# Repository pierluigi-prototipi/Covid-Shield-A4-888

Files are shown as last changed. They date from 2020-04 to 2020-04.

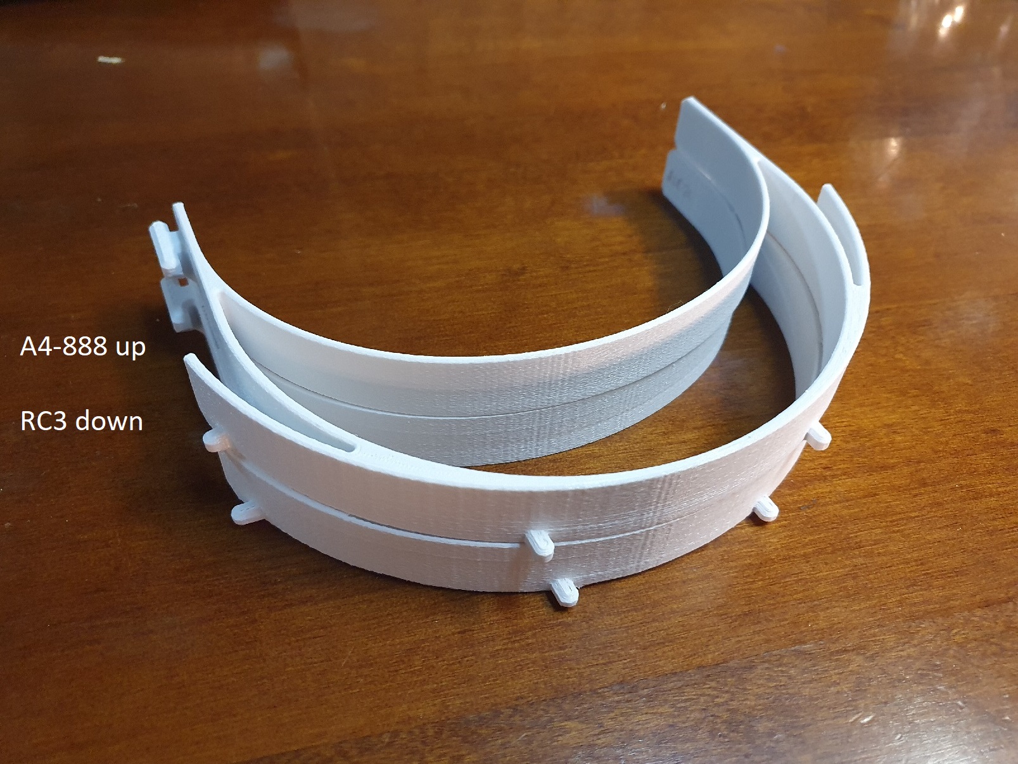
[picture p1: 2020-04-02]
confronto A4-888 vs RC3.jpg

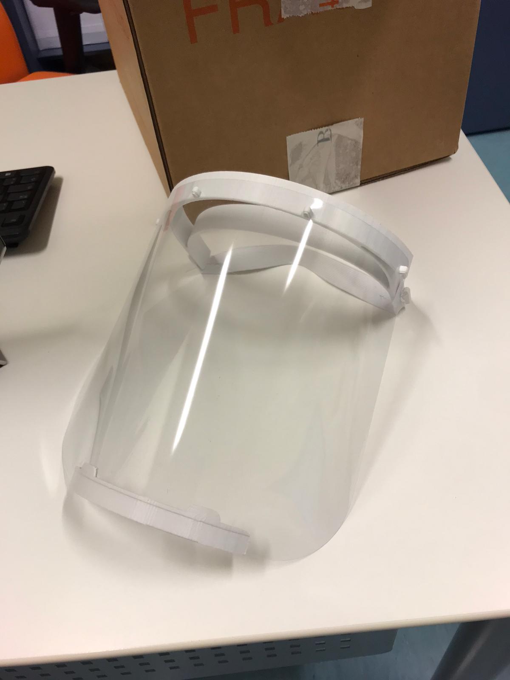
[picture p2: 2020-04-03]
foto scudo.jpeg

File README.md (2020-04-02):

# Covid-Shield-A4-888
A protective face shield based on A4 acetate sheet with holes spaced of 8 cm. You find more instructions on the pdf drawing.

The starting point of this design is the famous Prusa Protective FaceShield RC3. Because I found difficult to cut the holes on a A4 sheet in the correct position with the original design I modified it.
Here the major changes from the Prusa RC3:

HEAD-BAND:
1) It is larger in order to fit a 260 mm width sheet (I cut the A4 sheets, but if you prefer can leave them as they are)
2) The distance between the pins has been modified in order to fit a 8-8-8 cm preforated A4 sheet
3) The external pins are slightly shorter to simplify the linking to the sheet.
4) Removed all the slots, including the engraved writings, in order to avoid impurity retention.

Lower renforcement:
1) Now is a 2 pin design to make easier the punches on sheet.
2) The pin are longer and with two differnt slope on the upper and the lower side of the pins, to augment the stability on the sheet without reducing too much the ease of assembly.

SHIELD:
1) The starting point that I use is a common A4 acetate sheet, about 0.2 mm thick. Maybe a major thickness would be preferable.

THIS EQUIPMENT HAS NOT BEEN PROFESSIONALLY TESTED AND IS NOT CERTIFIED! Nevertheless I printed about twenty pieces in PLA and I find it usable, but this is just my opinion.

VERSIONE ITALIANA: 

 Visiera protettiva basata su foglio A4 in acetato con fori distanziati di 8 cm. Le istruzioni per tagliare i fogli sono disponibili     nel disegno pdf.

Il punto di partenza di questo progetto è il famoso Prusa Protector FaceShield RC3. Poichè ho trovato difficile eseguire i fori su un foglio A4 nella posizione corretta con il design originale, l'ho modificato, arrivando al modello che allego.
Ecco i principali cambiamenti rispetto al Prusa RC3:

FASCIA PER LA TESTA:
1) È leggermente più grande per adattarsi a un foglio di larghezza 260 mm (Rifilo i fogli A4 a 260 mm, ma se preferite si possono lasciare di 297 mm).
2) La distanza tra i perni è stata modificata per adattarsi a un foglio A4 preforato a 8-8-8 cm.
3) I pin esterni sono leggermente più corti per semplificare il collegamento al foglio.
4) Rimosse tutte le tasche, incluse le scritte incise, per evitare zone di possibile deposito di impurità.

Rinforzo inferiore:
1) Ora ha un design a 2 pin per facilitare la perforatura del foglio grazie all'utilizzo della spaziatura standard italiana di 8 cm.
2) I pin sono più lunghi e con due inclinazioni differenti sul bordo inferiore e superiore, al fine di rendere più solido il collegamento al foglio, senza compromettere eccessivamente la facilità di montaggio.

SCUDO:
1) Il punto di partenza è un comune foglio di acetato A4, spesso circa 0,2 mm. Forse sarebbe preferibile uno spessore maggiore.

QUESTO DISPOSITIVO NON E' STATO TESTATO PROFESSIONALMENTE E NON E' CERTIFICATO! Nonostante ciò ho stampato circa una ventina di pezzi in PLA e li trovo perfettamente utilizzabili. Ma questa è una mia opinione.

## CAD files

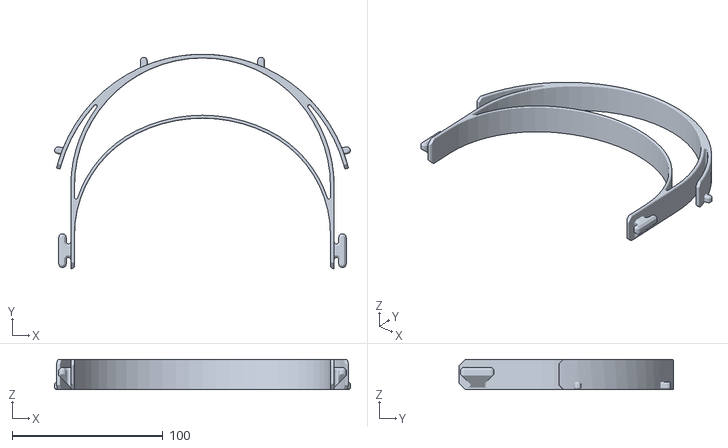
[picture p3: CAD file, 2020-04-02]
COVID_HEADBAND_A4-888_x1.stl
196.6 x 142.5 x 20.0

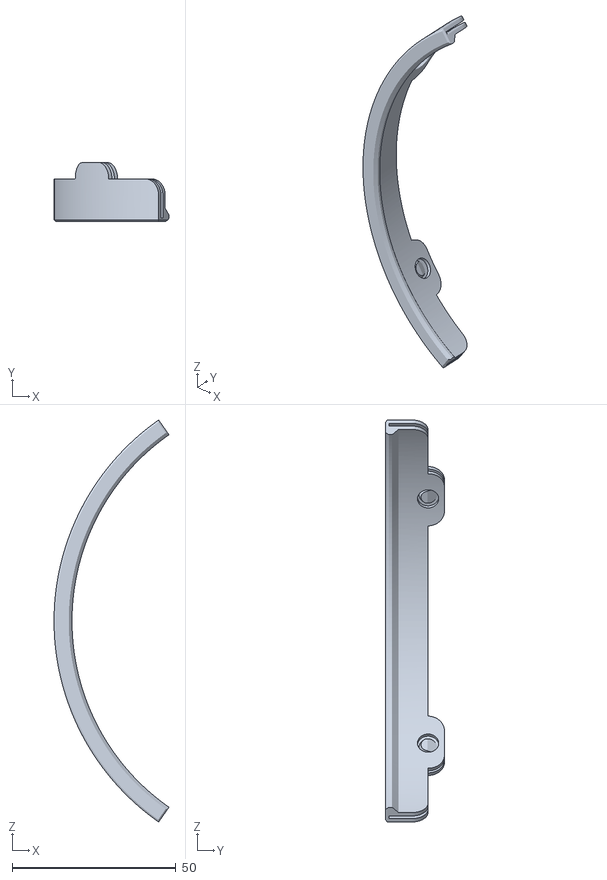
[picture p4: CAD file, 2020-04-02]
bottom_reinforcement_A4-888.stl
35.1 x 18.0 x 122.9

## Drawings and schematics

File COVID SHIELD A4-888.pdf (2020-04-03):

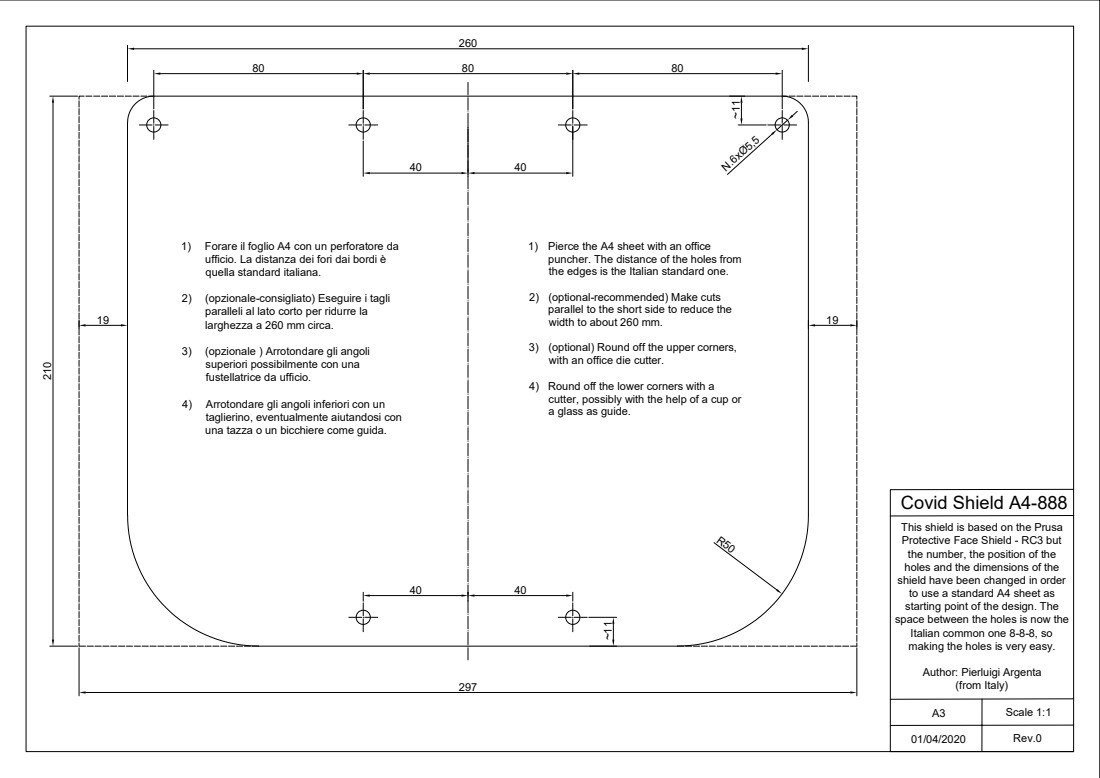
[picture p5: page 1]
297 ²¹⁰; Covid Shield A4-888; Rev.0; Scale 1:1

1) Forare il foglio A4 con un perforatore da
ufficio. La distanza dei fori dai bordi è
quella standard italiana.

1) Pierce the A4 sheet with an office
puncher. The distance of the holes from
the edges is the Italian standard one.

2) (optional-recommended) Make cuts
parallel to the short side to reduce the
width to about 260 mm.

2) (opzionale-consigliato) Eseguire i tagli
paralleli al lato corto per ridurre la
larghezza a 260 mm circa.

3) (optional) Round off the upper corners,
with an office die cutter.

3) (opzionale ) Arrotondare gli angoli
superiori possibilmente con una
fustellatrice da ufficio.

4) Round off the lower corners with a
cutter, possibly with the help of a cup or
a glass as guide.

4) Arrotondare gli angoli inferiori con un
taglierino, eventualmente aiutandosi con
una tazza o un bicchiere come guida.

This shield is based on the Prusa
Protective Face Shield - RC3 but
the number, the position of the
holes and the dimensions of the
shield have been changed in order
to use a standard A4 sheet as
starting point of the design. The
space between the holes is now the
Italian common one 8-8-8, so
making the holes is very easy.

Author: Pierluigi Argenta
(from Italy)
